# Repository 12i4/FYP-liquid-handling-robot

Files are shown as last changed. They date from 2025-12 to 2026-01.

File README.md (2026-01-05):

# FYP-liquid-handling-robot

This repository contains the complete hardware, firmware, and software implementation for an automated single-channel liquid-handling robot developed as part of an MEng Final Year Project. The system repurposes a decommissioned Raise3D Pro2 Plus motion platform into a programmable syringe-based pipetting robot with a Python control interface and optional GPT-assisted protocol generation.

The project focuses on low-cost laboratory automation, modular mechanical design, and a clear separation between mechanical actuation, firmware-level motion control, and high-level software abstraction.

---

## Repository Structure

The repository is organised into three main directories:

├── `hardware/`

├── `firmware/`

└── `software/`

Each directory corresponds to a major subsystem of the project and can be used independently for replication or further development.

---

## Hardware

**Directory:** `hardware/`

This directory contains the mechanical design files for the syringe pump, experimental deck, and adapters.

### Contents

- `Syringe Pump.f3d`
- `Pump Base.step`
- `Pump Carriage Sled.step`
- `Tips Adapter.f3d`
- `Tips Adapter.step`
- `Experiment Platform.f3d`
- `Experiment Platform.step`

### Description

The syringe pump mechanism used in this project is **adapted from the open-source Poseidon syringe pump project** developed by the Pachter Lab (https://github.com/pachterlab/poseidon), which is released under the **BSD 2-Clause License**.

The original Poseidon design served as a structural and conceptual baseline. The geometry, mounting interfaces, and overall assembly were **modified and reworked** to support integration with a modified Raise3D Pro2 Plus motion platform and to meet the requirements of automated liquid-handling operations in this project.

All CAD files are provided in both Fusion 360 (`.f3d`) and neutral STEP formats to support reuse, inspection, and modification in different CAD environments.

---

## Firmware

**Directory:** `firmware/`

### Contents

- `Marlin-btt/` – Modified Marlin firmware files including configuration files
- `firmware.bin` – Precompiled firmware image for direct flashing

### Description
The firmware is based on the open-source Marlin project (GPLv3).

Motion control is implemented using a BigTreeTech SKR Mini E3 V3.0 controller running a customised version of Marlin firmware. The firmware supports four stepper-driven axes (X, Y, Z, and U), sensorless homing via TMC2209 drivers, and motion constraints adapted for liquid-handling rather than 3D printing.

The provided `firmware.bin` can be flashed directly to the controller via SD card without recompilation. Users wishing to modify axis parameters, homing behaviour, or motion limits may edit the configuration files in `Marlin-btt/` and rebuild the firmware.

---

## Software

**Directory:** `software/`

### Description

The software stack is implemented in Python and follows a layered architecture:

- **robot.py**  
  Implements the command abstraction layer. Low-level G-code transmission and serial communication are wrapped into readable motion and liquid-handling primitives such as homing, point-to-point movement, aspiration, dispensing, and tip handling.

- **deck.py**  
  Defines the physical deck layout and slot coordinates. All labware placement is referenced relative to this model.

- **labware.py**  
  Encodes labware geometry (e.g. plates, tip racks, reservoirs) independently of motion logic, allowing new labware to be added without modifying control code.

- **gui.py**  
  A Tkinter-based graphical user interface providing manual jogging, homing, protocol execution, and real-time feedback, with optional GPT-assisted generation of JSON experiment protocols.

### Standalone Executable

An Windows executable (`PipetteRobot.exe`) included for demonstration purposes. This executable is packaged using PyInstaller and **does not require a Python environment** to run. Launching the executable starts the graphical user interface directly with all dependencies bundled.

---

## Usage Overview

1. Flash the provided firmware to the controller board.
2. Install the syringe, tip rack, and labware onto predefined deck slots.
3. Launch the GUI using either `gui.py` (Python environment) or `PipetteRobot.exe` (standalone).
4. Home the system and execute manual or automated protocols.

Detailed usage scenarios, experimental procedures, and evaluation results are documented in the accompanying project report.

---

## Project Scope and Disclaimer

This project is a research and educational prototype developed for academic purposes. It demonstrates the feasibility of low-cost laboratory automation and software–hardware integration. The system has not been validated for biological, chemical, or clinical use, and no claims are made regarding regulatory compliance.

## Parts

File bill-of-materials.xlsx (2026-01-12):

Syringe Pumps& Control Board
Part Number | Item Description | Package Cost | Items per pump | Cost per pump | Cost for single pump | Retailer | Items per pack | Price per item | Link
1 | Nema 17 Stepper Motor (42×40 mm, 1.8°, 1.5 A, 400 mN·m) | £11.97 | 1 | £11.97 | 11.97 | Amazon | 1 | 11.97 | https://www.amazon.co.uk/dp/B0753DS9FQ
2 | 5mm to 5mm Motor Shaft Coupling | £6.99 | 1 | £1.75 | 6.99 | Amazon | 4 | 1.7475 | https://www.amazon.co.uk/dp/B07NSVV22Z
3 | 6mm x 200mm Stainless Steel Round Rods | £7.59 | 2 | £3.79 | 7.59 | Amazon | 4 | 1.8975 | https://www.amazon.co.uk/dp/B0CD7RCZWM
4 | Sourcing map LM6UU Linear Ball Bearings (6mm) | £7.59 | 2 | £3.79 | 7.59 | Amazon | 4 | 1.8975 | https://www.amazon.co.uk/dp/B07H94WKPW
5 | Sourcing map Fully Threaded Rod M5 x 120mm 0.8mm | £5.59 | 1 | £1.86 | 5.59 | Amazon | 3 | 1.863333333 | https://www.amazon.co.uk/dp/B0DD7TMH78
6 | M5 nut | £4.79 | 2 | £0.48 | 4.79 | Amazon | 20 | 0.2395 | https://www.amazon.co.uk/dp/B08KPBSF3Q
7 | M3x0.5 socket head screws (20mm) | £5.99 | 8 | £0.40 | 5.99 | Amazon | 120 | 0.04991666667 | https://www.amazon.co.uk/dp/B0FC1HQZC4
8 | M3x0.5 socket head screws (75mm) | £4.99 | 4 | £3.33 | 4.99 | Amazon | 6 | 0.8316666667 | https://www.amazon.co.uk/dp/B0DFYLM9NP
9 | M3 nut | £3.99 | 4 | £0.32 | 3.99 | Amazon | 50 | 0.0798 | https://www.amazon.co.uk/3mm-Hex-Full-Nut-Stainless/dp/B0FFMXSCD5?s=industrial&s=industrial (https://www.amazon.com/100Pcs-Female-Thread-Fastener-Silver/dp/B00GYS1SXU?s=industrial)
12 | BIGTREETECH SKR Mini E3 V3.0 Control Board | £48.89 | 1 | £48.89 | 48.89 | Amazon | 1 | 48.89 | https://www.amazon.co.uk/dp/B09LQQP4RF
13 | PLA filament (~300 g) | £15/kg | 0.3kg | £4.50 | 4.5
14 | TPU filament (~1 g) | £15/kg | 0.002kg | £0.03 | 0.03
 |  | Single minimum system Price |  | £81.12
Labware
Part Number | Item Description | Package Cost | Items needed | Items per pack | Retailer | Link
1 | Filter Pipette tips 200uL 96Tips | £12.00 | 1 | 1 | Amazon | https://www.amazon.co.uk/dp/B0999CL2F1
2 | Plastic Syringes, 5pcs 1/2/5/10/20ml | £4.49 | 1 | 5 | Amazon | https://www.amazon.co.uk/dp/B0CMQBB46B
Printer
Part Number | Item Description | Package Cost
1 | Raise3D Pro 2 3D Printer | £1,400 - £2,600 |  | Prices from eBay accessed in Jan 2026.

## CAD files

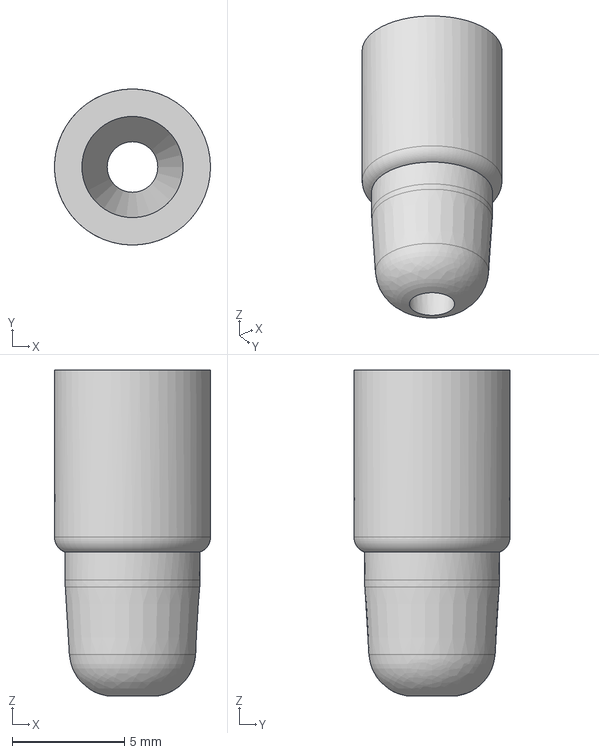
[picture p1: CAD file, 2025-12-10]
hardware/Tips Adapter.step
6.94 x 6.94 x 14.5 mm

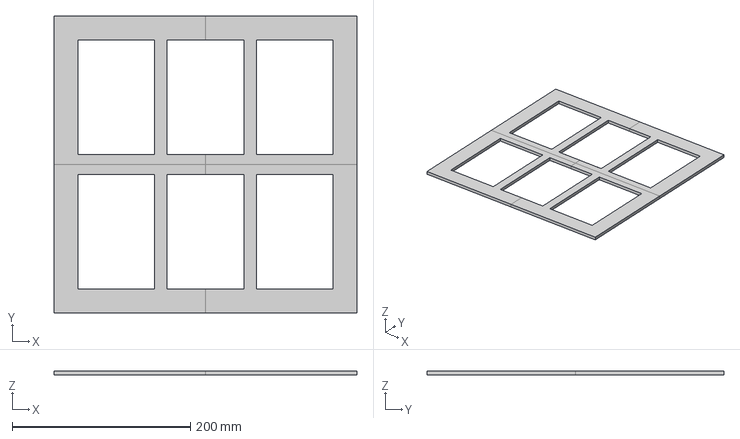
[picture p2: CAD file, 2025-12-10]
hardware/Experiment Platform.step
340.0 x 333.0 x 5.00 mm

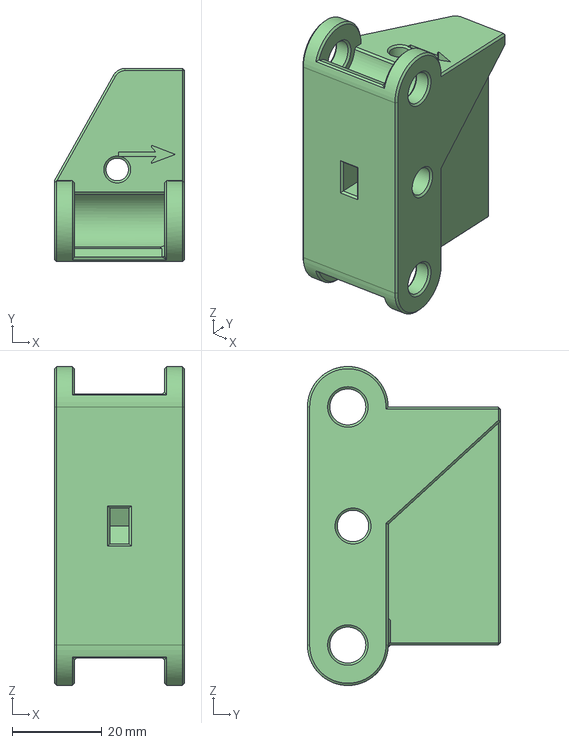
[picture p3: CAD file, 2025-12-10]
hardware/Pump Carriage Sled.step
29.0 x 43.0 x 71.0 mm

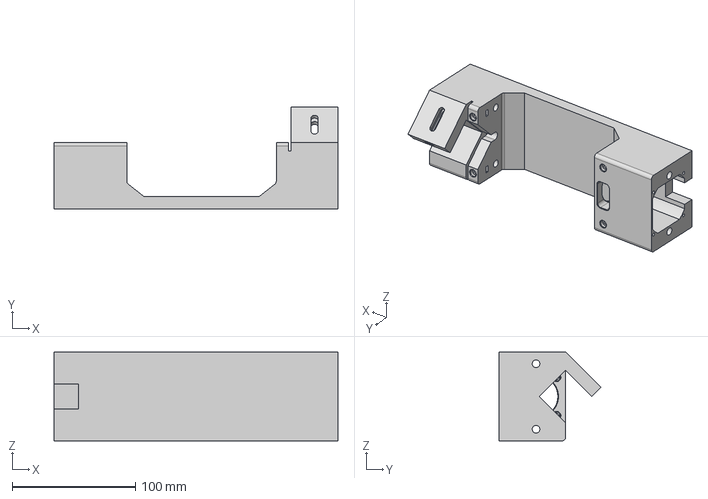
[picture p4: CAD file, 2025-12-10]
hardware/Pump Base.step
230.0 x 82.6 x 72.0 mm

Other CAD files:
hardware/Experiment Platform.f3d
hardware/Tips Adapter.f3d

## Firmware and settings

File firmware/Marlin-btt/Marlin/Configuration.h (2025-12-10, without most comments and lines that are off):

#pragma once
#define CONFIG_EXAMPLES_DIR "Creality/Ender-3/BigTreeTech SKR Mini E3 3.0"
#define CONFIGURATION_H_VERSION 02010205
#define STRING_CONFIG_H_AUTHOR "(BigTreeTech, Ender-3)" // Who made the changes.
#define SHOW_BOOTSCREEN
#define SHOW_CUSTOM_BOOTSCREEN
#define CUSTOM_STATUS_SCREEN_IMAGE
  #define MOTHERBOARD BOARD_BTT_SKR_MINI_E3_V3_0
#define SERIAL_PORT 2
#define BAUDRATE 115200
#define SERIAL_PORT_2 -1
#define CUSTOM_MACHINE_NAME "Ender-3"
#define X_DRIVER_TYPE  TMC2209
#define Y_DRIVER_TYPE  TMC2209
#define Z_DRIVER_TYPE  TMC2209
#define I_DRIVER_TYPE  TMC2209
  #define AXIS4_NAME 'U' // :['A', 'B', 'C', 'U', 'V', 'W']
#define EXTRUDERS 0
#define TEMP_SENSOR_0 0
#define TEMP_SENSOR_1 0
#define TEMP_SENSOR_2 0
#define TEMP_SENSOR_3 0
#define TEMP_SENSOR_4 0
#define TEMP_SENSOR_5 0
#define TEMP_SENSOR_6 0
#define TEMP_SENSOR_7 0
#define TEMP_SENSOR_BED 0
#define TEMP_SENSOR_PROBE 0
#define TEMP_SENSOR_CHAMBER 0
#define TEMP_SENSOR_COOLER 0
#define TEMP_SENSOR_BOARD 0
#define TEMP_SENSOR_REDUNDANT 0
#define DUMMY_THERMISTOR_998_VALUE  25
#define DUMMY_THERMISTOR_999_VALUE 100
#if TEMP_SENSOR_IS_MAX_TC(0)
  #define MAX31865_SENSOR_OHMS_0      100 // (Ω) Typically 100 or 1000 (PT100 or PT1000)
  #define MAX31865_CALIBRATION_OHMS_0 430 // (Ω) Typically 430 for Adafruit PT100; 4300 for Adafruit PT1000
#endif
#if TEMP_SENSOR_IS_MAX_TC(1)
  #define MAX31865_SENSOR_OHMS_1      100
  #define MAX31865_CALIBRATION_OHMS_1 430
#endif
#if TEMP_SENSOR_IS_MAX_TC(2)
  #define MAX31865_SENSOR_OHMS_2      100
  #define MAX31865_CALIBRATION_OHMS_2 430
#endif
#if HAS_E_TEMP_SENSOR
  #define TEMP_RESIDENCY_TIME         10  // (seconds) Time to wait for hotend to "settle" in M109
  #define TEMP_WINDOW                  1  // (°C) Temperature proximity for the "temperature reached" timer
  #define TEMP_HYSTERESIS              3  // (°C) Temperature proximity considered "close enough" to the target
#endif
#if TEMP_SENSOR_BED
  #define TEMP_BED_RESIDENCY_TIME     10  // (seconds) Time to wait for bed to "settle" in M190
  #define TEMP_BED_WINDOW              1  // (°C) Temperature proximity for the "temperature reached" timer
  #define TEMP_BED_HYSTERESIS          3  // (°C) Temperature proximity considered "close enough" to the target
#endif
#if TEMP_SENSOR_CHAMBER
  #define TEMP_CHAMBER_RESIDENCY_TIME 10  // (seconds) Time to wait for chamber to "settle" in M191
  #define TEMP_CHAMBER_WINDOW          1  // (°C) Temperature proximity for the "temperature reached" timer
  #define TEMP_CHAMBER_HYSTERESIS      3  // (°C) Temperature proximity considered "close enough" to the target
#endif
#if TEMP_SENSOR_REDUNDANT
  #define TEMP_SENSOR_REDUNDANT_SOURCE    E1  // The sensor that will provide the redundant reading.
  #define TEMP_SENSOR_REDUNDANT_TARGET    E0  // The sensor that we are providing a redundant reading for.
  #define TEMP_SENSOR_REDUNDANT_MAX_DIFF  10  // (°C) Temperature difference that will trigger a print abort.
#endif
#define HEATER_0_MINTEMP   5
#define HEATER_1_MINTEMP   5
#define HEATER_2_MINTEMP   5
#define HEATER_3_MINTEMP   5
#define HEATER_4_MINTEMP   5
#define HEATER_5_MINTEMP   5
#define HEATER_6_MINTEMP   5
#define HEATER_7_MINTEMP   5
#define BED_MINTEMP        5
#define CHAMBER_MINTEMP    5
#define HEATER_0_MAXTEMP 275
#define HEATER_1_MAXTEMP 275
#define HEATER_2_MAXTEMP 275
#define HEATER_3_MAXTEMP 275
#define HEATER_4_MAXTEMP 275
#define HEATER_5_MAXTEMP 275
#define HEATER_6_MAXTEMP 275
#define HEATER_7_MAXTEMP 275
#define BED_MAXTEMP      125
#define CHAMBER_MAXTEMP  60
#define HOTEND_OVERSHOOT 15   // (°C) Forbid temperatures over MAXTEMP - OVERSHOOT
#define BED_OVERSHOOT    10   // (°C) Forbid temperatures over MAXTEMP - OVERSHOOT
#define COOLER_OVERSHOOT  2   // (°C) Forbid temperatures closer than OVERSHOOT
#define PIDTEMP           // See the PID Tuning Guide at https://reprap.org/wiki/PID_Tuning
#define PID_MAX  255      // Limit hotend current while PID is active (see PID_FUNCTIONAL_RANGE below); 255=full current
#define PID_K1     0.95   // Smoothing factor within any PID loop
    #define DEFAULT_Kp  21.73
    #define DEFAULT_Ki   1.54
    #define DEFAULT_Kd  76.55
#define MAX_BED_POWER 255 // limits duty cycle to bed; 255=full current
#define PIDTEMPBED
  #define DEFAULT_bedKp 50.71
  #define DEFAULT_bedKi 9.88
  #define DEFAULT_bedKd 173.43
#define MAX_CHAMBER_POWER 255 // limits duty cycle to chamber heater; 255=full current
  #define PID_FUNCTIONAL_RANGE 10 // If the temperature difference between the target temperature and the actual temperature
#define PREVENT_COLD_EXTRUSION
#define EXTRUDE_MINTEMP 0
#define PREVENT_LENGTHY_EXTRUDE
#define EXTRUDE_MAXLENGTH 600
#define THERMAL_PROTECTION_HOTENDS // Enable thermal protection for all extruders
#define THERMAL_PROTECTION_BED     // Enable thermal protection for the heated bed
#define THERMAL_PROTECTION_CHAMBER // Enable thermal protection for the heated chamber
#define THERMAL_PROTECTION_COOLER  // Enable thermal protection for the laser cooling
#define USE_XMIN_PLUG
#define USE_YMIN_PLUG
#define USE_ZMIN_PLUG
#define USE_IMIN_PLUG
#define ENDSTOPPULLUPS
#define X_MIN_ENDSTOP_INVERTING false // Set to true to invert the logic of the endstop.
#define Y_MIN_ENDSTOP_INVERTING false // Set to true to invert the logic of the endstop.
#define Z_MIN_ENDSTOP_INVERTING true // Set to true to invert the logic of the endstop.
#define I_MIN_ENDSTOP_INVERTING false // Set to true to invert the logic of the endstop.
#define J_MIN_ENDSTOP_INVERTING false // Set to true to invert the logic of the endstop.
#define K_MIN_ENDSTOP_INVERTING false // Set to true to invert the logic of the endstop.
#define U_MIN_ENDSTOP_INVERTING false // Set to true to invert the logic of the endstop.
#define V_MIN_ENDSTOP_INVERTING false // Set to true to invert the logic of the endstop.
#define W_MIN_ENDSTOP_INVERTING false // Set to true to invert the logic of the endstop.
#define X_MAX_ENDSTOP_INVERTING false // Set to true to invert the logic of the endstop.
#define Y_MAX_ENDSTOP_INVERTING false // Set to true to invert the logic of the endstop.
#define Z_MAX_ENDSTOP_INVERTING false // Set to true to invert the logic of the endstop.
#define I_MAX_ENDSTOP_INVERTING false // Set to true to invert the logic of the endstop.
#define J_MAX_ENDSTOP_INVERTING false // Set to true to invert the logic of the endstop.
#define K_MAX_ENDSTOP_INVERTING false // Set to true to invert the logic of the endstop.
#define U_MAX_ENDSTOP_INVERTING false // Set to true to invert the logic of the endstop.
#define V_MAX_ENDSTOP_INVERTING false // Set to true to invert the logic of the endstop.
#define W_MAX_ENDSTOP_INVERTING false // Set to true to invert the logic of the endstop.
#define Z_MIN_PROBE_ENDSTOP_INVERTING false // Set to true to invert the logic of the probe.
#define ENDSTOP_INTERRUPTS_FEATURE
#define DEFAULT_AXIS_STEPS_PER_UNIT   { 80, 80, 800, 4000 }
#define DEFAULT_MAX_FEEDRATE          { 500, 500, 500, 500 }
#define DEFAULT_MAX_ACCELERATION      { 500, 500, 100, 100 }
#define DEFAULT_ACCELERATION           500    // X, Y, Z and E acceleration for printing moves
#define DEFAULT_RETRACT_ACCELERATION   500    // E acceleration for retracts
#define DEFAULT_TRAVEL_ACCELERATION    500    // X, Y, Z acceleration for travel (non printing) moves
#define DEFAULT_EJERK    5.0  // May be used by Linear Advance
  #define JUNCTION_DEVIATION_MM 0.08  // (mm) Distance from real junction edge
  #define JD_HANDLE_SMALL_SEGMENTS    // Use curvature estimation instead of just the junction angle
#define S_CURVE_ACCELERATION
#define NOZZLE_TO_PROBE_OFFSET { 10, 10, 0 }
#define PROBING_MARGIN 10
#define XY_PROBE_FEEDRATE (133*60)
#define Z_PROBE_FEEDRATE_FAST (4*60)
#define Z_PROBE_FEEDRATE_SLOW (Z_PROBE_FEEDRATE_FAST / 2)
#define Z_CLEARANCE_DEPLOY_PROBE   10 // (mm) Z Clearance for Deploy/Stow
#define Z_CLEARANCE_BETWEEN_PROBES  5 // (mm) Z Clearance between probe points
#define Z_CLEARANCE_MULTI_PROBE     5 // (mm) Z Clearance between multiple probes
#define Z_PROBE_LOW_POINT          -2 // (mm) Farthest distance below the trigger-point to go before stopping
#define Z_PROBE_OFFSET_RANGE_MIN -20
#define Z_PROBE_OFFSET_RANGE_MAX 20
#define X_ENABLE_ON 0
#define Y_ENABLE_ON 0
#define Z_ENABLE_ON 0
#define I_ENABLE_ON 0
#define DISABLE_OTHER_EXTRUDERS   // Keep only the active extruder enabled
#define INVERT_X_DIR false
#define INVERT_Y_DIR false
#define INVERT_Z_DIR true
#define INVERT_I_DIR true
#define INVERT_E0_DIR true
#define INVERT_E1_DIR false
#define INVERT_E2_DIR false
#define INVERT_E3_DIR false
#define INVERT_E4_DIR false
#define INVERT_E5_DIR false
#define INVERT_E6_DIR false
#define INVERT_E7_DIR false
#define X_HOME_DIR -1
#define Y_HOME_DIR -1
#define Z_HOME_DIR -1
#define I_HOME_DIR -1
#define X_BED_SIZE 305
#define Y_BED_SIZE 305
#define X_MIN_POS 0
#define Y_MIN_POS 0
#define Z_MIN_POS 0
#define X_MAX_POS X_BED_SIZE
#define Y_MAX_POS Y_BED_SIZE
#define Z_MAX_POS 605
#define I_MIN_POS 0
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

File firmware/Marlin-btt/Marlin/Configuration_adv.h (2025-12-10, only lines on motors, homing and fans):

  #define CONTROLLER_FAN_PIN FAN2_PIN       // Set a custom pin for the controller fan
#define E0_AUTO_FAN_PIN FAN1_PIN
#define E1_AUTO_FAN_PIN -1
#define E2_AUTO_FAN_PIN -1
#define E3_AUTO_FAN_PIN -1
#define E4_AUTO_FAN_PIN -1
#define E5_AUTO_FAN_PIN -1
#define E6_AUTO_FAN_PIN -1
#define E7_AUTO_FAN_PIN -1
#define CHAMBER_AUTO_FAN_PIN -1
#define COOLER_AUTO_FAN_PIN -1
#define HOMING_BUMP_MM      { 0, 0, 0, 0 }       // (linear=mm, rotational=°) Backoff from endstops after first bump
#define HOMING_BUMP_DIVISOR { 2, 2, 4, 2 }       // Re-Bump Speed Divisor (Divides the Homing Feedrate)
#define QUICK_HOME                            // If G28 contains XY do a diagonal move first
#define MICROSTEP_MODES { 16, 16, 16, 16, 16, 16 } // [1,2,4,8,16]
#define LIN_ADVANCE
    #define ADVANCE_K 0.0         // (mm) Compression length applying to all extruders
    #define X_CURRENT       580        // (mA) RMS current. Multiply by 1.414 for peak current.
    #define X_CURRENT_HOME  (X_CURRENT/2)  // (mA) RMS current for homing. (Typically lower than *_CURRENT.)
    #define X_MICROSTEPS     16        // 0..256
    #define Y_CURRENT       580
    #define Y_CURRENT_HOME  (Y_CURRENT/2)
    #define Y_MICROSTEPS     16
    #define Z_CURRENT       750
    #define Z_CURRENT_HOME  Z_CURRENT
    #define Z_MICROSTEPS     16
    #define I_CURRENT      750
    #define I_CURRENT_HOME I_CURRENT
    #define I_MICROSTEPS    16
  #define X_HYBRID_THRESHOLD     100  // [mm/s]
  #define X2_HYBRID_THRESHOLD    100
  #define Y_HYBRID_THRESHOLD     100
  #define Y2_HYBRID_THRESHOLD    100
  #define Z_HYBRID_THRESHOLD       3
  #define Z2_HYBRID_THRESHOLD      3
  #define Z3_HYBRID_THRESHOLD      3
  #define Z4_HYBRID_THRESHOLD      3
  #define I_HYBRID_THRESHOLD       3  // [linear=mm/s, rotational=°/s]
  #define J_HYBRID_THRESHOLD       3  // [linear=mm/s, rotational=°/s]
  #define K_HYBRID_THRESHOLD       3  // [linear=mm/s, rotational=°/s]
  #define U_HYBRID_THRESHOLD       3  // [mm/s]
  #define V_HYBRID_THRESHOLD       3
  #define W_HYBRID_THRESHOLD       3
  #define E0_HYBRID_THRESHOLD     30
  #define E1_HYBRID_THRESHOLD     30
  #define E2_HYBRID_THRESHOLD     30
  #define E3_HYBRID_THRESHOLD     30
  #define E4_HYBRID_THRESHOLD     30
  #define E5_HYBRID_THRESHOLD     30
  #define E6_HYBRID_THRESHOLD     30
  #define E7_HYBRID_THRESHOLD     30
  #define SENSORLESS_HOMING // StallGuard capable drivers only
    #define X_STALL_SENSITIVITY  75
    #define X2_STALL_SENSITIVITY X_STALL_SENSITIVITY
    #define Y_STALL_SENSITIVITY  50
    #define Y2_STALL_SENSITIVITY Y_STALL_SENSITIVITY
    #define I_STALL_SENSITIVITY  75
    #define IMPROVE_HOMING_RELIABILITY

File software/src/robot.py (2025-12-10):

# robot.py
"""
Robot control for the pipette platform.
用于控制移液机器人的核心类。

本文件提供两层能力：
1. 底层串口 / G-code 通讯与基础运动 (home / move_to / send_gcode 等)
2. 高层移液动作 (戴 tips / 蹭掉 tips / 移液 / 吸液 / 排液)

所有硬件参数（平台布局、器皿几何、Z 高度、注射器标定）
都集中在 deck.py 和 labware.py 中，这里不写死任何数值。
"""

from __future__ import annotations

import time
from typing import Optional

import serial

from src.deck import Deck
from src.labware import (
    LabwareType,  
    LabwareInstance,
    LABWARE_TIPRACK_96,
    LABWARE_TIPWASTE_BOX,
    LABWARE_48WELL_10MM,
    LABWARE_BEAKER_1WELL, 
    SYRINGES,
    SyringeType,
)


class Robot:
    """
    Robot wrapper around a Marlin-like firmware.

    面向用户的机器人控制类，封装：
    - 串口连接与 G-code 通讯
    - 轴运动（X/Y/Z/U）
    - 常用高层动作（戴 tip、扔 tip、移液、吸液、排液）

    使用方式示例：
    Example:
        from deck import Deck
        from robot import Robot

        deck = Deck()
        robot = Robot("COM4")
        robot.home(axes="XYZ")       # 只回 XYZ，避免 U 变形
        robot.set_absolute_mode()

        # 戴 tip：slot1 的 A1
        robot.pick_up_tip(deck, slot_id="1", well="A1")

        # 从 slot4.A1 吸 50µL 到 slot4.B3
        robot.transfer_volume(
            deck,
            src_slot="4", src_well="A1",
            dst_slot="4", dst_well="B3",
            volume_ul=50.0,
            syringe="10ml",
        )
    """

    # --------------------------------------------------
    # 初始化与串口管理 / Initialization & Serial I/O
    # --------------------------------------------------

    def __init__(
        self,
        port: str,
        baudrate: int = 115200,
        timeout: float = 1.0,
        auto_connect: bool = True,
    ) -> None:
        """
        Create a robot controller.

        创建机器人控制对象。

        Args:
            port:     串口号，例如 "COM4" 或 "/dev/ttyUSB0"
            baudrate: 波特率，通常为 115200
            timeout:  串口读超时（秒）
            auto_connect: 是否在构造时自动连接串口
        """
        self.port = port
        self.baudrate = baudrate
        self.timeout = timeout

        self._ser: Optional[serial.Serial] = None

        # 可选：当前平台与注射器信息（高层动作使用）
        # Optional: current deck and syringe settings
        self.deck: Optional[Deck] = None
        self.current_syringe: Optional[SyringeType] = None

        if auto_connect:
            self.connect()

    # ---------------------- Serial ---------------------

    def connect(self) -> None:
        """
        Open serial connection if not already open.

        打开串口连接（若尚未连接）。
        """
        if self._ser is not None and self._ser.is_open:
            return

        self._ser = serial.Serial(
            self.port,
            self.baudrate,
            timeout=self.timeout,
        )
        # 清空缓冲区，避免旧数据干扰
        self._flush_input()

    def disconnect(self) -> None:
        """
        Close serial connection.

        关闭串口连接。
        """
        if self._ser is not None:
            try:
                self._ser.close()
            except Exception:
                pass
            self._ser = None

    def _ensure_connected(self) -> None:
        """
        Ensure serial is open before any I/O.

        确保在进行读写前串口已经打开。
        """
        if self._ser is None or not self._ser.is_open:
            raise RuntimeError("Serial not connected. 未连接串口，请先调用 connect().")

    def _flush_input(self) -> None:
        """
        Flush any pending bytes from the input buffer.

        清空串口输入缓冲区，丢弃所有未读数据。
        """
        if self._ser is None:
            return
        self._ser.reset_input_buffer()

    def _write_line(self, line: str) -> None:
        """
        Write a line of G-code to the firmware.

        发送一行 G-code 到固件（自动添加换行）。
        """
        self._ensure_connected()
        data = (line.strip() + "\n").encode("ascii")
        self._ser.write(data)
        self._ser.flush()

    def _read_line(self) -> str:
        """
        Read a line from firmware (blocking up to timeout).

        从固件读取一行文本（阻塞直到 timeout）。
        """
        self._ensure_connected()
        raw = self._ser.readline()
        if not raw:
            return ""
        try:
            return raw.decode("ascii", errors="ignore").strip()
        except Exception:
            return ""

    def _drain_until_ok_or_timeout(self, overall_timeout: float) -> None:
        """
        Read lines until an 'ok' is received or timeout occurs.

        持续读取固件输出，直到收到 'ok' 或者超时。
        - 收到 'ok' → 正常返回
        - 收到 Error / error → 仍然抛 RuntimeError
        - 超时 → 只打印警告，不抛异常（避免 GUI 弹框）
        """
        start = time.time()
        while True:
            line = self._read_line()
            if line:
                # 简单调试输出：可根据需要保留或注释
                # print(f"[FW] {line}")
                if line.startswith("Error") or "error" in line.lower():
                    raise RuntimeError(f"Firmware error: {line}")
                if line.strip().lower() == "ok":
                    return
            # overall_timeout 为 None 或 <=0 时视为「无限等待」
            if overall_timeout is not None and overall_timeout > 0:
                if time.time() - start > overall_timeout:
                    # 超时：只给出一个终端 warning，然后返回，不抛 TimeoutError
                    print("[WARN] Timeout waiting for 'ok' from firmware, "
                          "ignore and continue.")
                    return

    # --------------------------------------------------
    # G-code 封装 / G-code wrapper
    # --------------------------------------------------

    def send_gcode(
        self,
        gcode: str,
        wait_ok: bool = True,
        overall_timeout: float = 9999.0,
    ) -> None:
        """
        Send a raw G-code command to the firmware.

        发送一条原始 G-code 指令到固件。

        Args:
            gcode:            要发送的 G-code 字符串（不含换行）
            wait_ok:          是否等待固件返回 'ok'
            overall_timeout:  等待 'ok' 的最长时间（秒）
        """
        self._write_line(gcode)
        if wait_ok:
            self._drain_until_ok_or_timeout(overall_timeout)

    def dwell(self, seconds: float) -> None:
        """
        Firmware-side dwell using G4.

        使用 G4 命令让固件等待指定时间（秒），
        比 Python 的 time.sleep 更安全，因为电机运动由固件控制。
        """
        ms = int(seconds * 1000)
        self.send_gcode(f"G4 P{ms}", wait_ok=True, overall_timeout=seconds + 5.0)

    # --------------------------------------------------
    # Homing / Coordinate Modes
    # --------------------------------------------------

    def home_all(self, timeout: float = 9999.0) -> None:
        """
        Home all axes with a plain G28.

        使用 G28 指令对所有轴进行回零。
        注意：Z 轴行程较长，默认使用较大的超时时间。
        """
        self.send_gcode("G28", wait_ok=True, overall_timeout=timeout)
        # ---------- 追加：把 U 轴抬起来以避免挤压注射器 ----------
        # 假设 U=5mm 是安全高度（避免变形）
        self.send_gcode("G1 U5 F200")
        # ---------------------------------------------------------

    def home(self, axes: str = "XYZU", timeout: float = 9999.0) -> None:
        """
        Home selected axes with G28.

        使用 G28 指令对指定轴回零。
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

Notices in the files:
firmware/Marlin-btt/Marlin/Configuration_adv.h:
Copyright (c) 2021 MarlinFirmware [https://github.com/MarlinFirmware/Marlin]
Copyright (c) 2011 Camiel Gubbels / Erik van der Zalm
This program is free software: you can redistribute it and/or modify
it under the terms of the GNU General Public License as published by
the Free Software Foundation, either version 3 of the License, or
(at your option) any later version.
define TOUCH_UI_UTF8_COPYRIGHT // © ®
